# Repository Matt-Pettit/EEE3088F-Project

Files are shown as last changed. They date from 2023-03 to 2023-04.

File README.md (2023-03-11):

# 🌡️ HAT for STM32F0: Temperature & Humidity Monitoring

# EEE3088F Group Project 10

Welcome to our **EEE3088F Group Project** repository! This repository contains all the project files for our HAT designed for the STM32F0 microcontroller. 

## 🚀 Project Overview

The primary functionality of the HAT is to monitor external environmental conditions using a digital Temperature and Humidity Sensor, along with an analogue light sensor (LDR)

This HAT has a wide range of potential applications. It would be particularly useful in monitoring for satisfactory growth conditions of plants in an agricultural setting. Secondly, the HAT may aid with maintaining optimum food and beverage storage conditions and therein reducing the amount of consumables that perish. Lastly, the HAT may be set to trigger air conditioning units and dehumidifiers in hospitals such that the patients may recuperate in a steady environment. 

## 🛠️ Hardware

The HAT is designed to attach to the STM32F051C6T6 microcontroller. The board includes circuitry to control power, the ability to be soft programmed and a standard pin interface on which the HAT will connect. 

## 🤝 Contributors

This project is being developed by three contributors:

- Queto Jenkins (Power Module)
- Holly Lewis (Sensor Module)
- Matt Pettit (Coding and Microcontroller Interfacing)

## 📁 Repository Contents

This repository contains the following files and folders:

- `README.md`: this file
- `Design-files`: folder containing the design files for the HAT
- `Source-code`: folder containing the source code for the HAT
- `LICENSE`: file containing license information
- `Bill Of Materials.xlsx`: BOM for this project

## 📝 License

This project is licensed under the GNU General Public License. See the LICENSE file for more information.

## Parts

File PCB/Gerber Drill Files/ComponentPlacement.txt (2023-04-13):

Info: Front (top side) placement file: '/Users/queto/UNIVERSITY/Third Year/First Semester/EEE3088F/EEE3088F-Project/Design-files/Main/Main-top.pos'.
Info: Component count: 57.
Info: Back (bottom side) placement file: '/Users/queto/UNIVERSITY/Third Year/First Semester/EEE3088F/EEE3088F-Project/Design-files/Main/Main-bottom.pos'.
Info: Component count: 0.
Info: Full component count: 57.
Info: File generation successful.
Info: Front (top side) placement file: '/Users/queto/UNIVERSITY/Third Year/First Semester/EEE3088F/EEE3088F-Project/PCB/Gerber Drill Files/Main-top.pos'.
Info: Component count: 57.
Info: Back (bottom side) placement file: '/Users/queto/UNIVERSITY/Third Year/First Semester/EEE3088F/EEE3088F-Project/PCB/Gerber Drill Files/Main-bottom.pos'.
Info: Component count: 0.
Info: Full component count: 57.
Info: File generation successful.
Info: Front (top side) placement file: '/Users/queto/UNIVERSITY/Third Year/First Semester/EEE3088F/EEE3088F-Project/PCB/Gerber Drill Files/Main-top.pos'.
Info: Component count: 57.
Info: Back (bottom side) placement file: '/Users/queto/UNIVERSITY/Third Year/First Semester/EEE3088F/EEE3088F-Project/PCB/Gerber Drill Files/Main-bottom.pos'.
Info: Component count: 0.
Info: Full component count: 57.
Info: File generation successful.

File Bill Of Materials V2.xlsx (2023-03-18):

BILL OF MATERIALS |  |  |  |  |  |  |  | Version 2.0
SUBSYSTEM | PART | PART REFERENCE | LCSC PART NUMBER | PART NAME | LINK TO PART | EXTENDED? | COST | NUMBER NEEDED | LINE COST
microcontroller module | USB to Serial | U1 | C84681 | CH340C | https://jlcpcb.com/partdetail/wch_jiangsu_Qin_heng-CH340C/C84681 | 1 | 0.47 | 1 | 0.47
microcontroller module | USB _Micro | J1 | C404969 | C404969 --- MicroXNJ | https://jlcpcb.com/partdetail/ShouHan-MicroXNJ/C404969 | 1 | 0.03 | 1 | 0.03
microcontroller module | EEEPROM | U2 | C79988 | M24C64-RMN6TP | https://jlcpcb.com/partdetail/Stmicroelectronics-M24C64RMN6TP/C79988 | 1 | 0.43 | 1 | 0.43
microcontroller module | Conn_01x10_Pin | J7 | C124380 | B-2100S06P-A110 | https://jlcpcb.com/partdetail/125655-B_2100S06PA110/C124380 | 0 | 0.1 | 2 | 0.2
microcontroller module | Conn_01x24_Pin | J3, J6 | C124380 | B-2100S06P-A110 | https://jlcpcb.com/partdetail/125655-B_2100S06PA110/C124380 | 0 | 0.1 | 2 | 0.2
microcontroller module | Conn_01x24_Socket | J4, J5 | C350289 | 2685Y-240CNG1MNA01 | https://jlcpcb.com/partdetail/Hoauc-2685Y240CNG1MNA01/C350289 | 0 | 0.1 | 2 | 0.2
power module | Battery Management Charger | U6 | C32574 | TP4054-42-SOT25R | https://jlcpcb.com/partdetail/33539-TP4054_42SOT25R/C32574 | 0 | 0.14 | 1 | 0.14
power module | Voltage Regulator | U7 | C250432 | RT9073A-33GQZ | https://jlcpcb.com/partdetail/RichtekTech-RT9073A33GQZ/C250432 | 1 | 0.13 | 1 | 0.13
power module | Battery Cell | BT1 | C2979183 | MY-18650-01 | https://jlcpcb.com/partdetail/Myoung-MY_1865001/C2979183 | 0 | 0.31 | 1 | 0.31
power module | 10uF Capacitor | C1, C7 | C19702 | CL10A106KP8NNNC | https://jlcpcb.com/partdetail/20411-CL10A106KP8NNNC/C19702 | 0 | 0.01 | 2 | 0.02
power module | Conn_01x02_PIn | J9, J13 | C124380 | B-2100S06P-A110 | https://jlcpcb.com/partdetail/125655-B_2100S06PA110/C124380 | 0 | 0.1 | 2 | 0.2
power module | D_Schottky | D1 | C2480 | SS14 | https://jlcpcb.com/partdetail/mdd_microdiode_electronics-SS14/C2480 | 0 | 0.01 | 1 | 0.01
power module | Power Switching IC | U6 | C140321 | TPS2115ADRBR | https://jlcpcb.com/partdetail/TexasInstruments-TPS2115ADRBR/C140321 | 1 | 1.75 | 1 | 1.75
power module | Resistor 10k | R 4 | C17414 | 0805W8F1002T5E | https://jlcpcb.com/parts/2nd/Resistors/Chip_Resistor_Surface_Mount_4 | 0 | 0.01 | 1 | 0.01
power module | Resistor 680 | R 5 | C23228 | 0603WAF6800T5E | https://jlcpcb.com/partdetail/23955-0603WAF6800T5E/C23228 | 0 | 0.01 | 7 | 0.07
power module | 0.1uF Capacitor | C3, C4, C8, C9 | C24497 | CL31B104KBCNNNC | https://jlcpcb.com/partdetail/25237-CL31B104KBCNNNC/C24497 | 0 | 0.01 | 4 | 0.04
power module | Resistor 2k | R11, R12 | C17944 | 1206W4F2001T5E | https://jlcpcb.com/partdetail/18632-1206W4F2001T5E/C17944 | 0 | 0.01 | 2 | 0.02
power module | Resistor 4.7k | R19, R20 | C25940 | 0402WGJ0472TCE | https://jlcpcb.com/partdetail/26683-0402WGJ0472TCE/C25940 | 0 | 0.01 | 2 | 0.02
power module | 1uF Capacitor | C2, C5, C6 | C52923 | CL05A105KA5NQNC | https://jlcpcb.com/partdetail/53938-CL05A105KA5NQNC/C52923 | 0 | 0.01 | 3 | 0.03
power module | Charging Status Red LED | ChargingStatusLED1 | C84256 | NCD0805R1 | https://jlcpcb.com/partdetail/85425-NCD0805R1/C84256 | 0 | 0.01 | 1 | 0.01
power module | Battery Jumper Connector_PinHeader_2.54mm | J2 | C124380 | B-2100S06P-A110 | https://jlcpcb.com/partdetail/125655-B_2100S06PA110/C124380 | 0 | 0.01 | 1 | 0.01
power module | Resistor 0 | R6, R7, R8, R9, R10, R13, R14, R15, R16, R17, R18, R21, R22, R23, R24, R25, R26 | C21376 | 0402WGJ0000TCE | https://jlcpcb.com/partdetail/22093-0402WGJ0000TCE/C21376 | 1 | 0.01 | 17 | 0.01
power module | Resistor 1k | R1, Rprog | C52199 | 1206W4F1001T5 | https://jlcpcb.com/partdetail/uni_royal_uniroyal_elec-1206W4F1001T5/C4410 | 0 | 0.01 | 2 | 0.02
sensor module | Humidity and Temperature Sensor | U3 | C194656 | SHTC3 | https://jlcpcb.com/partdetail/Sensirion-SHTC3/C194656 | 1 | 0.95 | 1 | 0.95
sensor module | Resistor 150k |  | C25755 | 0402WGF1503TCE | https://jlcpcb.com/partdetail/26498-0402WGF1503TCE/C25755 | 0 | 0.01 | 1 | 0.01
 |  |  |  |  | TOTAL COST (excl. Extended) | TOTAL NUMBER OF EXTENDED PARTS | TOTAL COST FOR FIVE BOARDS
 |  |  |  | Microcontroller | 1.53 | 3 | 16.65
 |  |  |  | Power Module | 2.76 | 3 | 22.8
 |  |  |  | Sensor Module | 0.01 | 1 | 3.05
 |  |  |  |  |  | Total Parts Cost | 42.5
 |  |  |  |  |  | Total Assembly Cost | 54.5
 |  |  |  |  |  | Remaining Budget | 15.5

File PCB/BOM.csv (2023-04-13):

Id | Designator | Footprint | Quantity | Designation | Supplier and ref
1 | C3,C4 | C1206 | 2 | 0.1 uF
2 | U4 | TSOT-23-5 | 1 | LTC4054ES5-4.2
3 | R9,R23,R13,R14,R28,R24,R10,R22,R7,R27,R18,R8,R15,R25,R6,R21,R17,R16 | R0402 | 18 | 0
4 | R4 | R0603 | 1 | 700
5 | C1,C7 | C0603 | 2 | 10 uF
6 | R19,R20 | R0402 | 2 | 4.7k
7 | C2,C10,C11 | C0402 | 3 | 1 uF
8 | J13,J9 | PinHeader_1x02_P2.54mm_Vertical | 2 | Conn_01x02_Pin
9 | U6 | SON-8_L3.0-W3.0-P0.65-LS3.0-BL-EP | 1 | TPS2115ADRBR
10 | C8 | C_0201_0603Metric | 1 | 0.1uF
11 | Rprog1,R1 | R1206 | 2 | 1k
12 | J3-Left1,J6-Right1 | PinHeader_1x24_P2.54mm_Vertical | 2 | Conn_01x24_Pin
13 | U1 | SOP-16_L10.0-W3.9-P1.27-LS6.0-BL | 1 | CH340C
14 | C6,C5 | C1206 | 2 | 0.1uF
15 | StatusLED | LED0805-RD | 1 | LED
16 | BT1 | BatteryHolder_Keystone_1042_1x18650 | 1 | Battery_Cell
17 | R12,R11 | R0805 | 2 | 10k
18 | J2 | PinHeader_1x02_P2.54mm_Vertical | 1 | Battery Jumper
19 | J8 | PinHeader_1x04_P2.54mm_Vertical | 1 | Conn_01x04_Pin
20 | U3 | Sensirion_DFN-4-1EP_2x2mm_P1mm_EP0.7x1.6mm | 1 | SHTC3
21 | R2,R3 | R_0201_0603Metric | 2 | 100K
22 | J4-Left1,J5-Right1 | PinSocket_1x24_P2.54mm_Vertical | 2 | Conn_01x24_Socket
23 | J1 | USB_Mini-B_Lumberg_2486_01_Horizontal | 1 | USB_B_Micro
24 | J7 | PinHeader_1x10_P2.54mm_Vertical | 1 | Conn_01x10_Pin
25 | U7 | SOIC-8_L5.0-W4.0-P1.27-LS6.0-BL | 1 | M24C64-RMN6TP
26 | R5 | R0805 | 1 | 10K
27 | U5 | ZQFN-4L_L1.0-W1.0-P0.63-BL-EP | 1 | RT9073A-33GQZ
28 | D1 | SMA_L4.2-W2.6-LS5.3-RD | 1 | D_Schottky

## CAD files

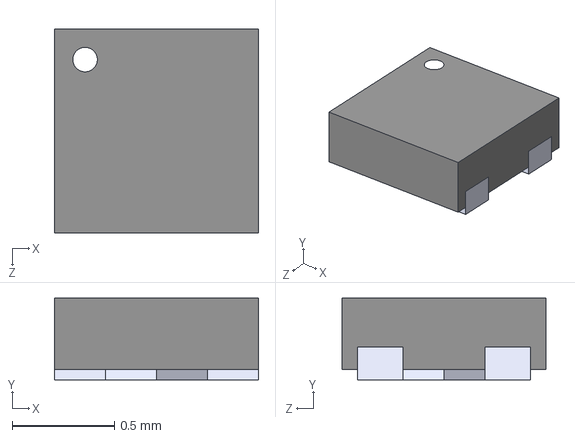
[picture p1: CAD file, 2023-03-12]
Design-files/Main/REG_RT9080-33GQZ/REG_RT9080-33GQZ.step
1.00 x 0.4 x 1.00 mm

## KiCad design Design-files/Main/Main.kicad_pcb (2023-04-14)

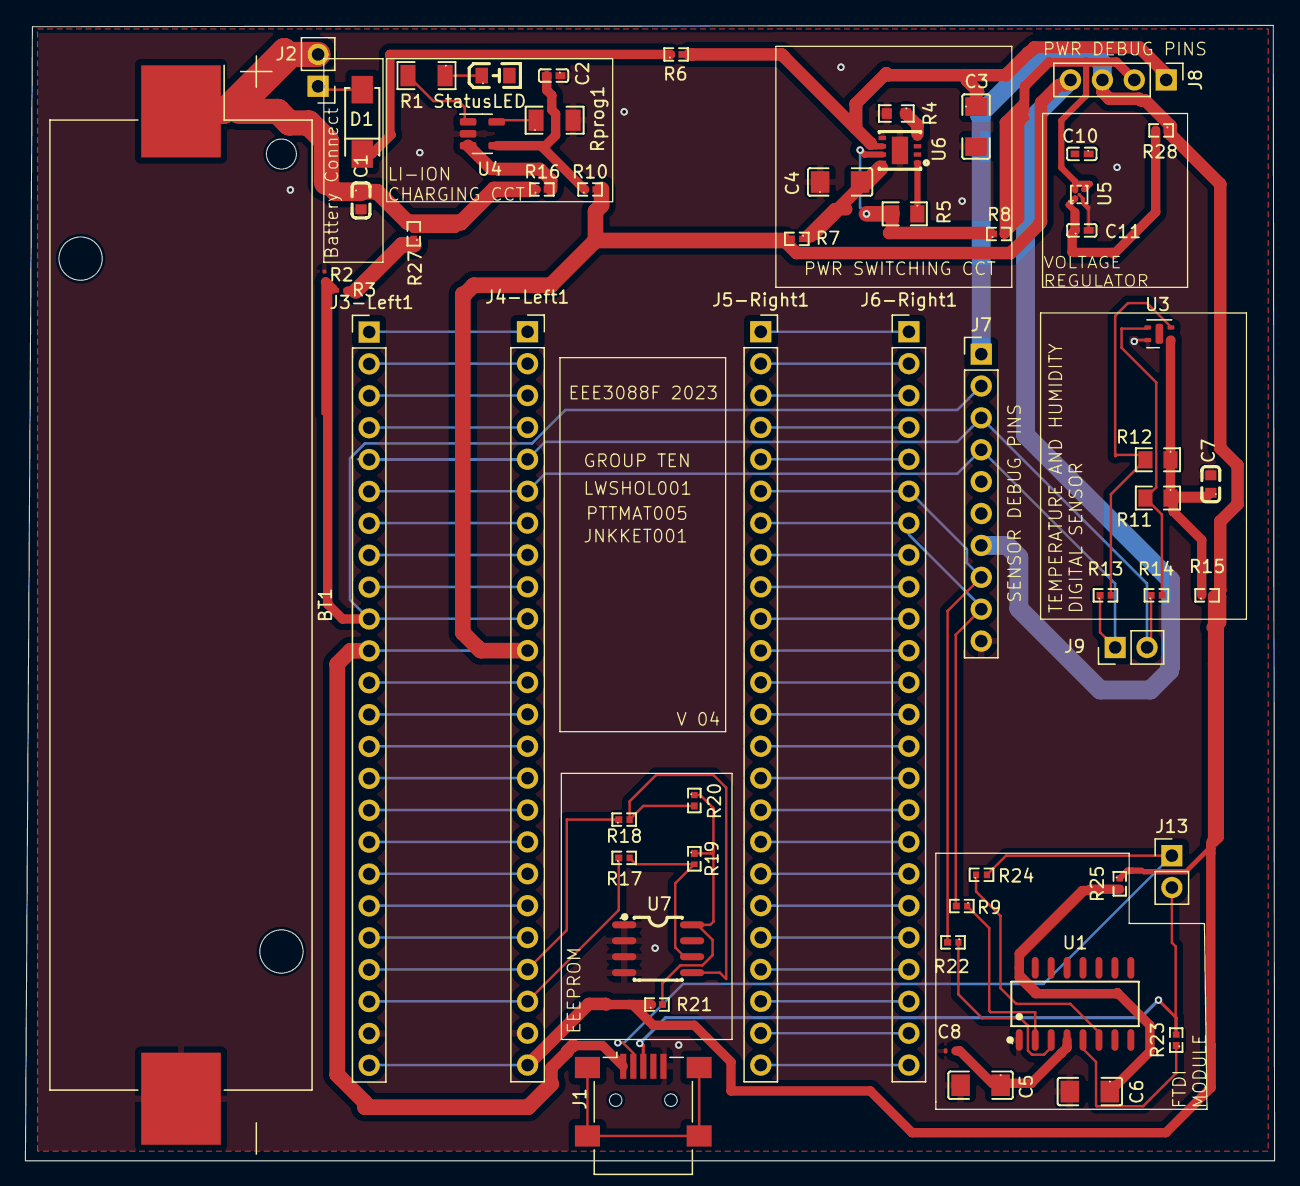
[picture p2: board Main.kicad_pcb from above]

Board: 2 copper layers, 99.5 x 90.4 mm, 57 parts (0 on the bottom side), 78 nets.

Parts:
BT1: Battery_Cell; BatteryHolder_Keystone_1042_1x18650
C1, C7: 10 uF; C0603
C2, C10, C11: 1 uF; C0402
C3, C4: 0.1 uF; C1206
C5, C6: 0.1uF; C1206
C8: 0.1uF; C_0201_0603Metric
D1: D_Schottky; SMA_L4.2-W2.6-LS5.3-RD
J1: USB_B_Micro; USB_Mini-B_Lumberg_2486_01_Horizontal
J2: Battery Jumper; PinHeader_1x02_P2.54mm_Vertical
J3-Left1, J6-Right1: Conn_01x24_Pin; PinHeader_1x24_P2.54mm_Vertical
J4-Left1, J5-Right1: Conn_01x24_Socket; PinSocket_1x24_P2.54mm_Vertical
J7: Conn_01x10_Pin; PinHeader_1x10_P2.54mm_Vertical
J8: Conn_01x04_Pin; PinHeader_1x04_P2.54mm_Vertical
J9, J13: Conn_01x02_Pin; PinHeader_1x02_P2.54mm_Vertical
R1: 1k; R1206
R2, R3: 100K; R_0201_0603Metric
R4: 700; R0603
R5: 10K; R0805
R6, R7, R8, R9, R10, R13, R14, R15, R16, R17, R18, R21, R22, R23, R24, R25, R27, R28: 0; R0402
R11, R12: 10k; R0805
R19, R20: 4.7k; R0402
Rprog1: 1k; R1206
StatusLED: LED; LED0805-RD
U1: CH340C; SOP-16_L10.0-W3.9-P1.27-LS6.0-BL
U3: SHTC3; Sensirion_DFN-4-1EP_2x2mm_P1mm_EP0.7x1.6mm
U4: LTC4054ES5-4.2; TSOT-23-5
U5: RT9073A-33GQZ; ZQFN-4L_L1.0-W1.0-P0.63-BL-EP
U6: TPS2115ADRBR; SON-8_L3.0-W3.0-P0.65-LS3.0-BL-EP
U7: M24C64-RMN6TP; SOIC-8_L5.0-W4.0-P1.27-LS6.0-BL

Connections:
/BatterySense: J3-Left1.10, J4-Left1.10, J7.2, R2.1, R3.2
/DigitalSensorSCL: J3-Left1.6, J4-Left1.6, J7.4, J9.1, R13.1
/DigitalSensorSDA: J3-Left1.5, J4-Left1.5, J7.3, J9.2, R14.1
/Interfacing/EEPROMSCL: J3-Left1.21, J4-Left1.21, R18.1
/Interfacing/EEPROMSDA: J3-Left1.22, J4-Left1.22, R17.1
/Interfacing/USART_RX: J5-Right1.7, J6-Right1.7, J7.9, R9.2
/Interfacing/USART_TX: J5-Right1.6, J6-Right1.6, J7.8, R22.2
/Interfacing/USB D+: J1.3 (D+), J13.2, R23.2
/Interfacing/USB D-: J1.2 (D-), J13.1, R24.2
/Power Module/Battery Input Polarity Protection: C3.1, J8.1, R6.2, U6.6 (IN2)
/Power Module/Switched Power: J8.2, R8.2, U5.3 (EN), U5.4 (VIN)
/Regulated 3v3: J3-Left1.24, J4-Left1.24, J7.1, J8.3, R15.2, R21.1, R25.1, R28.1
/USB 5V: J1.1 (VBUS), J3-Left1.11, J4-Left1.11, J7.7, J8.4, R7.2, R10.2
Battery: BT1.1 (+), C1.1, J2.2, R16.1, R27.2
GND: BT1.2 (-), C1.2, C2.1, C3.2, C4.1, C5.2, C6.2, C7.2, C8.2, C11.2, J1.5 (GND), J3-Left1.23, J4-Left1.23, J7.10, R2.2, R4.2, Rprog1.2, U1.1 (GND), U3.4 (VSS), U4.2 (GND), U5.2 (GND), U5.5 (SGND), U6.5 (GND), U6.9 (GND), U7.1 (A0), U7.2 (A1), U7.3 (A2), U7.4 (VSS)
unnamed: C4.2, R7.1, U6.8 (IN1)
unnamed: R19.1, R20.1, R21.2, U7.8 (VCC)
unnamed: C2.2, R10.1, U4.4 (V_{CC})
unnamed: C7.1, R11.1, R12.1, R15.1, U3.1 (VDD)
unnamed: R1.1, StatusLED.1 (K)
unnamed: D1.2 (A), J2.1
unnamed: D1.1 (K), R6.1
unnamed: J3-Left1.1, J4-Left1.1
unnamed: J3-Left1.2, J4-Left1.2
unnamed: J3-Left1.3, J4-Left1.3
unnamed: J3-Left1.4, J4-Left1.4
unnamed: J3-Left1.7, J4-Left1.7
unnamed: J3-Left1.8, J4-Left1.8
unnamed: J3-Left1.9, J4-Left1.9
unnamed: J3-Left1.12, J4-Left1.12
unnamed: J3-Left1.13, J4-Left1.13
unnamed: J3-Left1.14, J4-Left1.14
unnamed: J3-Left1.15, J4-Left1.15
unnamed: J3-Left1.16, J4-Left1.16
unnamed: J3-Left1.17, J4-Left1.17
unnamed: J3-Left1.18, J4-Left1.18
unnamed: J3-Left1.19, J4-Left1.19
unnamed: J3-Left1.20, J4-Left1.20
unnamed: J5-Right1.1, J6-Right1.1
unnamed: J5-Right1.2, J6-Right1.2
unnamed: J5-Right1.3, J6-Right1.3
unnamed: J5-Right1.4, J6-Right1.4
unnamed: J5-Right1.5, J6-Right1.5
unnamed: J5-Right1.8, J6-Right1.8
unnamed: J5-Right1.9, J6-Right1.9
unnamed: J5-Right1.10, J6-Right1.10
unnamed: J5-Right1.11, J6-Right1.11
unnamed: J5-Right1.12, J6-Right1.12
unnamed: J5-Right1.13, J6-Right1.13
unnamed: J5-Right1.14, J6-Right1.14
unnamed: J5-Right1.15, J6-Right1.15
unnamed: J5-Right1.16, J6-Right1.16
unnamed: J5-Right1.17, J6-Right1.17
unnamed: J5-Right1.18, J6-Right1.18
unnamed: J5-Right1.19, J6-Right1.19
unnamed: J5-Right1.20, J6-Right1.20
unnamed: J5-Right1.21, J6-Right1.21
unnamed: J5-Right1.22, J6-Right1.22
unnamed: J5-Right1.23, J6-Right1.23
unnamed: J5-Right1.24, J6-Right1.24
unnamed: R3.1, R27.1
unnamed: R23.1, U1.5 (D+)
unnamed: R24.1, U1.6 (D-)
unnamed: R22.1, U1.3 (RXD)
unnamed: R9.1, U1.2 (TXD)
unnamed: C5.1, C8.1, U1.4 (V3)
unnamed: C6.1, R25.2, U1.16 (VCC)
unnamed: R12.2, R13.2, U3.2 (SCL)
unnamed: R11.2, R14.2, U3.3 (SDA)
unnamed: R16.2, U4.3 (BAT)
unnamed: Rprog1.1, U4.5 (PROG)
unnamed: R1.2, U4.1 (~CHRG)
unnamed: C11.1, R28.2, U5.1 (VOUT)
unnamed: R4.1, U6.4 (ILIM)
unnamed: R5.2, R8.1, U6.7 (OUT)
unnamed: R5.1, U6.1 (STAT)
unnamed: R17.2, R19.2, U7.6 (SCL)
unnamed: R18.2, R20.2, U7.5 (SDA)

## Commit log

2023-03-04 Schematic Changes
    [Main.csv, Main.kicad_pcb, Main.kicad_sch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]
2023-03-11 Lots of changes :)
    [Main.csv, Main.kicad_pcb, Main.kicad_sch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]
2023-03-11 Create CAD
2023-03-11 i am trying to maek a CAD folder
2023-03-12 Generated New BOM
    [Main.csv]
2023-03-13 The updated BOM
    [Bill Of Materials V2.xlsx]
2023-03-18 lets go team
    [Main.kicad_pcb, interfacing.kicad_sch, power.kicad_sch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]
2023-03-20 lots of changes
    [Main.kicad_pcb, interfacing.kicad_sch, power.kicad_sch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]
2023-03-20 the labeling blocks added
    [Main.kicad_pcb]
2023-03-21 biggest change of my life
    [Main-B_Cu.gbr, Main-B_Mask.gbr, Main-B_Paste.gbr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]
2023-04-13 fixed shematic
    [Main.kicad_pcb, interfacing.kicad_sch, power.kicad_sch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]
2023-04-13 gerbiees and silkscrenno
    [Main-B_Adhesive.gbr, Main-B_Cu.gbr, Main-B_Mask.gbr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]
2023-04-13 zippy stuff for submission
    [BOM.csv]
2023-04-13 drill files again
    [Main-B_Adhesive.gbr, Main-B_Cu.gbr, Main-B_Mask.gbr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]
2023-04-14 bom changes
    [BOM.csv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]
2023-04-14 new zipped bom for the third final submission
2023-04-14 with lscs part numbees
    [BOM.csv]
2023-04-14 last changes
    [BOM.csv]
